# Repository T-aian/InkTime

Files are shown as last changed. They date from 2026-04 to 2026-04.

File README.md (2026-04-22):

# Documentație de Arhitectură și Inginerie Hardware: Sistemul Wearable InkTime

## 1. Introducere

Proiectul InkTime reprezintă o inițiativă tehnologică ambițioasă de a dezvolta un smartwatch open-source, optimizat pentru costuri reduse și manufacturabilitate la scară largă, fără a face compromisuri în ceea ce privește fiabilitatea sau performanța.

### 1.1. Structura Proiectului

- **Hardware/**: Găzduiește definițiile fundamentale ale circuitului. Aici se regăsesc fișierul schematic (.sch), alături de fișierul board-ului (.brd).
- **Manufacturing/**: Conține arhiva esențială pentru fabrica de PCB-uri (gerbers.zip), care include straturile de cupru, măștile de lipire (solder mask), stratul de inscripționare (silkscreen) și fișierele de găurire (Excellon drill files). De asemenea, acest director include fișierul Bill of Materials (.bom), detaliind componentele utilizate, și fișierul Pick and Place (.cpl), care mapează coordonatele carteziene (X, Y) și rotația fiecărei componente pentru echipamentele automate de asamblare.
- **Mechanical/**: Include modelul 3D integrat al dispozitivului în format .step și format nativ Fusion360. Acest model cuprinde PCB-ul populat cu componente, geometria exactă a bateriei Li-Po, ecranul LCD, motorul haptic (shaker) și șasiul carcasei într-o vizualizare detaliată de tip "exploded view".
- **Images/**: Un director vizual care conține randări fotorealiste ale PCBA-ului (Printed Circuit Board Assembly) și ilustrează modul de potrivire mecanică a plăcii în carcasă, servind drept ghid vizual pentru procedurile de asamblare manuală.

## 2. Arhitectura de Sistem și Diagrama Bloc

Filosofia de design a smartwatch-ului InkTime se bazează pe o topologie modulară, distribuită în jurul unui nod central de procesare (System-on-Chip). Diagrama bloc de mai jos ilustrează interconectarea magistralelor de date, a traseelor de putere și a modulelor periferice. Sistemul este împărțit în patru domenii funcționale majore: Domeniul de Putere (Power Tree), Domeniul de Procesare și Comunicație RF, Domeniul Senzorial și Domeniul Interfeței cu Utilizatorul (UI/HMI).

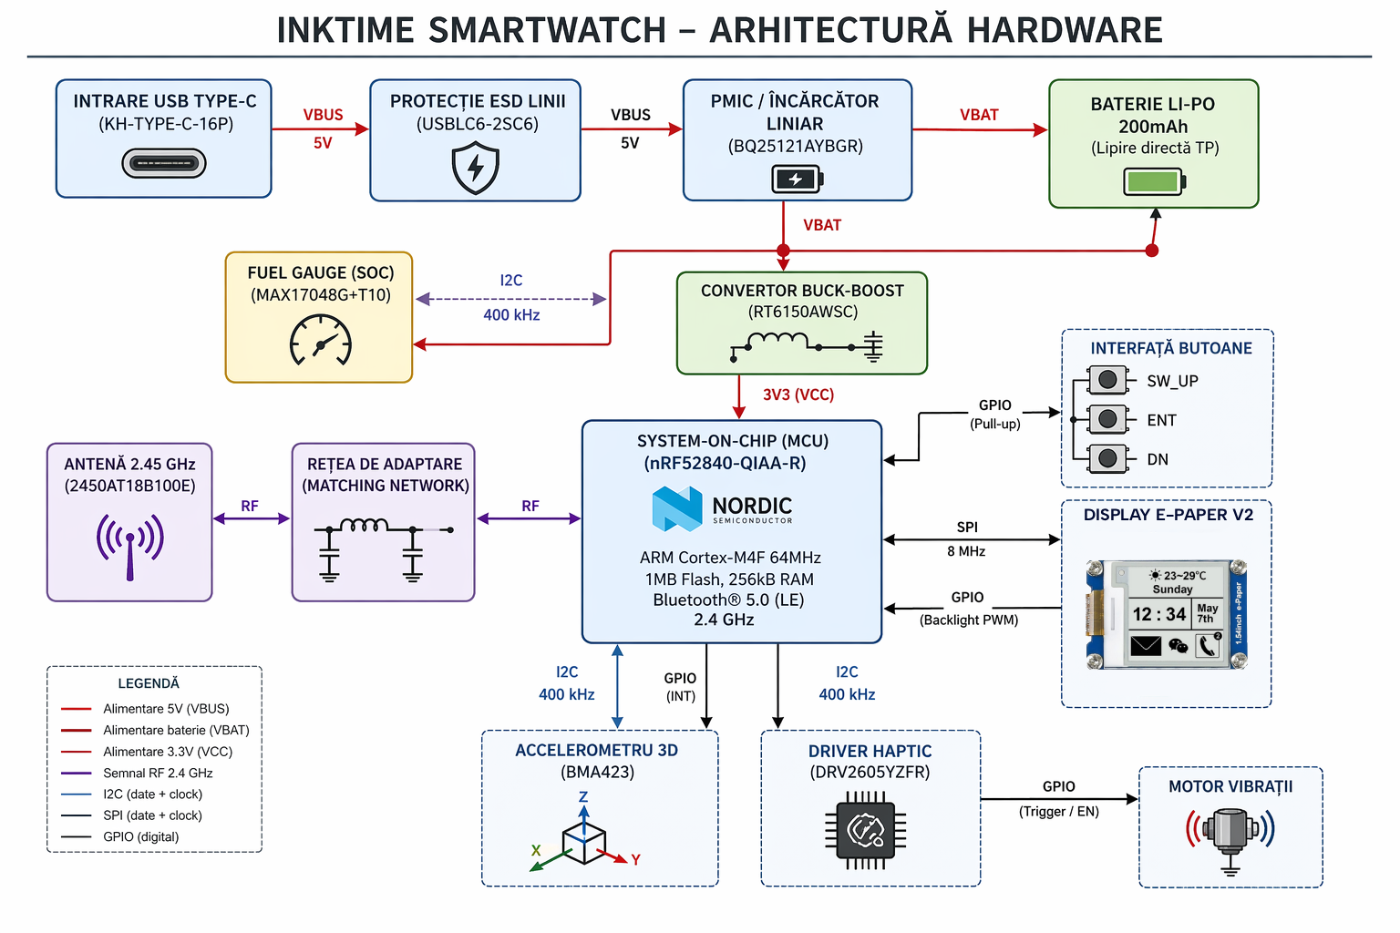
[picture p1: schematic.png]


Fluxul de operare este dictat de nRF52840, care gestionează stările de energie (Power States) ale întregului sistem. Modulul comunică asincron prin magistrala I2C (Inter-Integrated Circuit) cu senzorii (BMA423 pentru detecția mișcării, MAX17048 pentru starea bateriei, DRV2605 pentru feedback haptic) și sincron prin magistrala SPI (Serial Peripheral Interface) cu ecranul LCD. Etajul de alimentare separă procesul de încărcare (gestionat autonom de BQ25121A) de procesul de reglare a tensiunii (gestionat de RT6150AWSC), asigurând o tensiune logică de 3.3V indiferent de nivelul de descărcare al bateriei.

## 3. Bill of Materials (BOM)
Realizarea unui dispozitiv de masă la un cost competitiv impune o selecție a componentelor ancorată puternic în realitățile lanțului de aprovizionare (Supply Chain). Toate componentele majore au fost selectate din biblioteca producătorului asiatic JLCPCB, favorizând componentele "Basic" sau "Extended" aflate constant în stoc, evitând astfel întârzierile de aprovizionare.

De asemenea, pachetele fizice (footprints) au fost alese pentru a permite un asamblaj automatizat de mare viteză pe mașinile Pick and Place, respectând totodată cerința impusă de a utiliza exclusiv pachete SMD (Surface Mount Device).

| Componentă | Descriere funcțională | JLCPCB Part # | Link JLCPCB | Datasheet |
| --- | --- | --- | --- | --- |
| nRF52840-QIAA-R | System-on-Chip (SoC) ARM Cortex-M4F 64MHz, transceiver Bluetooth 5.0, 1MB Flash, 256KB RAM, pachet AQFN-73 | C190794 | [Link JLCPCB](https://jlcpcb.com/partdetail/NordicSemicon-NRF52840_QIAAR/C190794) | [https://files.seeedstudio.com/wiki/XIAO-BLE/Nano_BLE_MCU-nRF52840_PS_v1.1.pdf](https://files.seeedstudio.com/wiki/XIAO-BLE/Nano_BLE_MCU-nRF52840_PS_v1.1.pdf) |
| MAX17048G+T10 | Fuel Gauge pentru baterii Li-Ion (1 celulă), algoritm ModelGauge, interfață I2C, pachet TDFN-8 | C2682616 | [Link JLCPCB](https://jlcpcb.com/partdetail/C2682616) | [https://www.analog.com/media/en/technical-documentation/data-sheets/max17048-max17049.pdf](https://www.analog.com/media/en/technical-documentation/data-sheets/max17048-max17049.pdf) |
| BMA423 | Accelerometru MEMS triaxial, 12 biți, step counter hardware, pachet LGA-12 | C189517 | [Link JLCPCB](https://www.lcsc.com/product-detail/C189517.html) | [https://watchy.sqfmi.com/assets/files/BST-BMA423-DS000-1509600-950150f51058597a6234dd3eaafbb1f0.pdf](https://watchy.sqfmi.com/assets/files/BST-BMA423-DS000-1509600-950150f51058597a6234dd3eaafbb1f0.pdf) |
| DRV2605YZFR | Driver haptic smart-loop pentru motoare ERM/LRA, librărie Immersion, pachet DSBGA-9 | C81079 | [Link JLCPCB](https://www.lcsc.com/product-detail/C81079.html) | [https://www.ti.com/lit/ds/symlink/drv2605.pdf](https://www.ti.com/lit/ds/symlink/drv2605.pdf) |
| BQ25121AYBGR | PMIC + încărcător Li-Po ultra low power (max 300mA), Ship Mode, pachet DSBGA-25 | C111776 | [Link JLCPCB](https://jlcpcb.com/parts) | [https://www.ti.com/lit/ds/symlink/bq25121a.pdf](https://www.ti.com/lit/ds/symlink/bq25121a.pdf) |
| RT6150AWSC | Convertor DC-DC buck-boost (1.8V–5.5V → 3.3V), curent max 800mA, consum idle 60µA | C147971 | [Link JLCPCB](https://www.lcsc.com/product-detail/C147971.html) | [https://www.richtek.com/assets/product_file/RT6150A=RT6150B/DS6150AB-04.pdf](https://www.richtek.com/assets/product_file/RT6150A=RT6150B/DS6150AB-04.pdf) |
| KH-TYPE-C-16P | Conector USB Type-C mamă, 16 pini, SMD, profil redus, 3A | C709357 | [Link JLCPCB](https://jlcpcb.com/partdetail/KH-TYPE-C-16P/C709357) | N/A |
| USBLC6-2SC6 | Protecție ESD (TVS diode array), capacitance 2.5pF pentru linii USB | C7519 / C2827654 | [Link JLCPCB](https://jlcpcb.com/partdetail/STMicroelectronics-USBLC62SC6/C7519) | [https://www.st.com/resource/en/datasheet/usblc6-2.pdf](https://www.st.com/resource/en/datasheet/usblc6-2.pdf) |
| 2450AT18B100E | Antenă ceramică RF 2.45 GHz, eficiență ~76%, pachet SMD 1206 | C2836414 | [Link JLCPCB](https://jlcpcb.com/partdetail/JohansonTechnology-2450AT18B100/C2836414) | [https://www.johansontechnology.com/docs/1187/2450AT18B100_X8XXogU.pdf](https://www.johansontechnology.com/docs/1187/2450AT18B100_X8XXogU.pdf) |

## 4. Descrierea Exhaustivă a Funcționalității Hardware
Sistemul hardware a fost proiectat având ca prioritate absolută optimizarea balanței dintre performanța de calcul, capacitatea de interacțiune umană fluidă și un consum energetic de tip "ultra-low power". Modul în care aceste subsisteme interacționează determină direct fezabilitatea comercială a smartwatch-ului InkTime.
### 4.1. Nucleul de Procesare și Comunicație RF (nRF52840)
La baza sistemului se află integratul nRF52840-QIAA-R, un System-on-Chip (SoC) hibrid care combină logica unui microcontroler cu un transceiver radio de mare performanță. Funcționând la o frecvență de bază de 64 MHz, nucleul ARM Cortex-M4 include o unitate de calcul în virgulă mobilă (FPU - Floating Point Unit), esențială pentru procesarea accelerată a datelor senzoriale tridimensionale (cum ar fi cele generate de BMA423) și randarea elementelor grafice pe afișaj. Dispune de 1 MB memorie Flash internă și 256 KB memorie SRAM. Spațiul generos de memorie Flash permite integrarea sistemelor de operare de tip RTOS (precum Zephyr, frecvent utilizat în comunitatea open-source smartwatch) și implementarea de actualizări Over-The-Air (OTA) sigure.

Componenta de radiofrecvență a SoC-ului este extrem de performantă, suportând tehnologia Bluetooth 5.0 Low Energy (BLE), alături de protocoale precum Thread, Zigbee și rețele proprietare de 2.4 GHz. Dispozitivul are o sensibilitate de recepție de -95 dBm la 1 Mbps și poate emite semnale la o putere configurabilă de la -20 dBm până la +8 dBm. Această versatilitate asigură că ceasul poate menține o legătură stabilă cu un terminal mobil (ex. smartphone) chiar și în medii electromagnetice congestionate, minimizând totodată consumul bateriei adaptând puterea de transmisie. Securitatea pachetelor de date BLE este garantată de coprocesorul intern ARM TrustZone CryptoCell 310, care realizează criptare hardware AES/ECB asincron, degrevând procesorul principal.

Antena ceramică tip SMD (2450AT18B100E) este montată la extremitatea plăcii și este un dispozitiv de tip LTCC (Low Temperature Co-fired Ceramic), proiectat de Johanson Technology. Oferind o eficiență de 76%, antena necesită un design restrictiv al planului de masă pentru a nu-și altera impedanța caracteristică de 50 Ohmi.

### 4.2. Topologia de Alimentare și Managementul Bateriei (Power Delivery Network)

Tensiunea unei baterii clasice Litiu-Polimer (Li-Po) fluctuează considerabil în timpul ciclului său de descărcare, de la o valoare maximă de ~4.2V (complet încărcată) până la o tensiune de cut-off de aproximativ 3.0V. Pentru ca ecranul IPS și procesorul să ruleze constant, au nevoie de o sursă stabilă de energie. Aici intervine arhitectura "Power Tree" a dispozitivului InkTime.

### Etajul de Încărcare și Protecție (BQ25121A și USBLC6-2SC6):

Energia pătrunde în sistem prin intermediul conectorului KH-TYPE-C-16P, o versiune orizontală SMD care susține curenți nominali ridicați și care a fost preferată pentru profilul său plat. Liniile de date și alimentare ale portului USB sunt expuse mediului extern, devenind vulnerabile la descărcări electrostatice (ESD). Circuitul USBLC6-2SC6, conectat imediat după port, clamp-ează aceste tensiuni tranzitorii violente (clamping voltage de 17V) redirecționându-le în masă. Cu o capacitanță parazită de numai 2.5pF, acest cip nu degradează integritatea semnalului.

Tensiunea de 5V preluată (VBUS) este apoi rutată către circuitul de management al bateriei BQ25121AYBGR. Acest IC ultra-integrat a fost selectat în detrimentul soluțiilor clasice (precum TP4056) datorită capabilităților avansate de gestionare I2C și a unui consum de repaus (quiescent current) neglijabil. BQ25121A poate încărca bateria cu un curent controlat (maxim 300 mA), implementând ciclul standard CC-CV (Constant Current / Constant Voltage), dar mai important, dispune de un "Ship Mode". Prin activarea acestui mod, ceasul poate fi complet deconectat electronic de la baterie în timpul transportului și stocării în depozite, scăzând consumul bateriei sub 50nA, eliminând astfel riscul ca produsul să ajungă la consumator cu bateria "moartă".

### Etajul de Reglare a Tensiunii (RT6150AWSC):

Întreaga placă electronică funcționează la tensiunea standard de 3.3V (VCC / 3V3). Pentru a prelua variația bateriei de la 3.0V la 4.2V și a furniza constant 3.3V fără a disipa restul de putere ca pierdere termică (așa cum ar face un regulator liniar LDO), a fost integrat convertorul DC-DC Buck-Boost RT6150AWSC. Frecvența sa de comutație de 1 MHz permite utilizarea unor componente pasive magnetice (inductoare) mult mai mici, vitale pentru un design de tip smartwatch. Convertorul dispune de un "Power Save Mode" (PSM), care, în perioadele de consum redus, își scade frecvența de operare și trage din baterie un curent pasiv de doar 60 µA, menținând eficiențe mari la curenți mici.

### Monitorizarea Autonomiei (MAX17048G+T10):
În mod tradițional, monitorizarea capacității unei baterii implică inserarea unui rezistor tip "shunt" (coulomb counter) pe traseul de retur, ceea ce introduce pierderi resistive constante. InkTime utilizează integratul MAX17048G+T10. Acest fuel-gauge citește exclusiv tensiunea celulei (VCELL) și folosește un model matematic proprietar (ModelGauge™) pentru a estima Starea de Încărcare (State-of-Charge / SOC) cu o toleranță a erorii extrem de redusă, raportând datele către nRF52840 pe magistrala I2C. Prin eliminarea rezistorului de măsurare și o stare internă "Hibernate" în care consumă doar 3 µA, se economisește spațiu vital pe PCB și energie prețioasă.

### 4.3. Modulul Senzorial (Accelerometrul BMA423)
Pentru monitorizarea cinematică a purtătorului s-a implementat accelerometrul MEMS digital BMA423, proiectat de Bosch Sensortec. Acest senzor din clasa senzorilor "inteligenți" a fost creat special pentru industria wearable. În locul eșantionării constante și transferării a mii de pachete de date brute (Raw Acceleration Data) pe magistrala I2C către MCU – proces ce ar drena rapid bateria – BMA423 dispune de logică procesuală internă.
Funcția sa nativă de pedometru (Step Counter) analizează algoritmic tiparele de accelerație și numără pașii independent, menținând un consum total de putere redus până la pragul de 13 µA – 25 µA. Informația este stocată într-un buffer intern (FIFO de 1 kByte) de unde poate fi interogată ocazional de MCU. Suplimentar, funcțiile hardware de recunoaștere a mișcării identifică acțiunile de ridicare a brațului spre ochi ("Tilt-on-Wrist") sau bătăi ("Tap/Double Tap") și emit un impuls asincron pe un pin de întrerupere dedicat (INT), ordonând procesorului nRF52840 să iasă din modul System OFF/ON Sleep.

### 4.5. Feedback Haptic Avansat (DRV2605YZFR)

Alerta tactilă a utilizatorului trebuie să fie precisă, evitându-se "zgomotul" tactil al motoarelor dezechilibrate tradiționale. Implementarea include integratul DRV2605YZFR de la Texas Instruments, un driver haptic de înaltă finețe în pachet miniatural DSBGA (chip-scale package). Acest circuit, comunicând prin I2C, integrează o arhitectură de control "Smart-Loop" ce scurtează masiv timpii de accelerare (Startup Time ~ 0.7ms) și frânare ai motorului.
Mecanismul intern monitorizează constant forța contra-electromotoare (BEMF) indusă de motor pe liniile de acționare. Printr-o secvență de calibrare automată, DRV2605 detectează frecvența de rezonanță mecanică a actuatoarelor de tip LRA (Linear Resonant Actuator) și le acționează precis pe acea frecvență, extrăgând forță vibratorie dublă și economisind până la 50% din energia pe care ar fi risipit-o un driver liniar clasic cu punte H. Integratul include o memorie pre-încărcată cu peste 100 de efecte tactile licențiate de compania Immersion, permițând dezvoltatorilor software să selecteze simplu (via I2C) profilul de vibrație dorit (e.g., un „click” scurt de confirmare, o vibrație lungă de alertă), în loc să folosească comutații PWM manuale de la microcontroler. Când nu rulează nicio secvență, consumul driver-ului decade la sub 2 µA.

## 5. Alocarea și Justificarea Mapării Pinilor la nRF52840

SoC-ul nRF52840 oferă o matrice flexibilă (crossbar) pentru alocarea funcțiilor periferice (I2C, SPI, UART, PWM) către majoritatea pinilor GPIO. Cu toate acestea, această libertate este guvernată de reguli fizice imuabile detaliate în Specificațiile de Produs Nordic. Anumiți pini (e.g. P0.02, P0.03, P0.30, P1.15 etc.) sunt clasați arhitectural ca "Standard drive, low frequency I/O only", fiind optimizați exclusiv pentru semnale care nu depășesc 10 kHz. Ignorarea acestei limitări și forțarea unor magistrale rapide (cum ar fi clock-ul SPI la 8 MHz) pe acești pini va conduce la distorsiuni de formă a undei, diafonie radio (interferențe cu semnalul BLE de 2.4GHz) și emisii electromagnetice care pot eșua un test de certificare FCC/CE.

## 6. Analiza Bugetului Energetic și Estimarea Autonomiei Bateriei
Pentru a garanta că proiectul InkTime reprezintă o alternativă fezabilă pe piață, trebuie obținut un echilibru delicat între volumul intern restrâns al dispozitivului – care dictează utilizarea unei baterii Li-Po miniaturale de aproximativ 200 mAh (tensiune nominală 3.7V, tensiune maximă 4.2V) – și consumul diverselor componente electronice.

Mai jos prezentăm un calcul teoretic detaliat al consumului, divizat în cele două stări absolute de utilizare: Starea de Repaus (Sleep Mode) și Starea Activă (Peak Load). Calculele sunt preluate din informațiile stricte oferite de foile de catalog oficiale (Datasheets).

### 6.1. Consumul în Modul de Repaus (System Sleep State)

Un smartwatch își petrece majoritatea timpului (~90–95%) în stare de repaus, cu ecranul oprit. În acest mod:

- sistemul rulează în System ON Sleep (specific nRF52840)
- RAM-ul rămâne alimentat
- RTC-ul este activ
- BLE funcționează în mod Advertising periodic

Consum:
| Componentă | Consum tipic | Condiție / Justificare |
| --- | --- | --- |
| nRF52840 SoC | ~1.5 µA | System ON, CPU în WFI (Wait For Interrupt), RTC activ |
| Radio BLE | ~3.8 µA | Advertising periodic (interval ~10s) |
| BMA423 | ~13.0 µA | Low-power mode, sampling redus (~50 Hz), step detection activ |
| MAX17048 | ~3.0 µA | Hibernate mode, măsurători rare |
| DRV2605 | ~1.75 µA | Standby complet (shutdown) |
| BQ25121A | ~0.7 µA | Leakage cu USB deconectat |
| RT6150AWSC | ~60.0 µA | Quiescent current (DC-DC activ în Power Save Mode) |
| PCB (rezidual) | ~10.0 µA | Leakage pasive + pull-up-uri I2C |

**Consum total:** 
`TOTAL SLEEP ≈ 93.75 µA (0.093 mA)`

### 6.2. Consumul în Mod Activ (Peak Load State)

În modul activ (utilizatorul interacționează cu ceasul):
- display-ul este aprins
- BLE transmite date
- motorul haptic poate fi activ

| Componentă | Consum Peak  | Condiție / Justificare |
| --- | --- | --- |
| Display e-ink | ~5 – 15 mA (peak) | Doar în timpul refresh-ului (~200–500 ms). Consum ≈ 0 între refresh-uri |
| nRF52840 (CPU + BLE) | ~4.8 – 15 mA | TX BLE + procesare SPI pentru display |
| BMA423 | ~0.15 mA | High-performance mode (gesturi complexe) |
| DRV2605 + motor | ~60 – 80 mA  | Vibrație activă (ERM/LRA startup) |

**Consum total:** 
`TOTAL ACTIVE ≈ 10 – 90 mA`

### 6.3 Durată de viață Estimativă

Pe baza bugetelor de consum estimate, autonomia sistemului poate fi aproximată considerând un scenariu realist de utilizare: ~95% din timp în modul sleep (~0.093 mA) și ~5% în modul activ (~50 mA mediu). Curentul mediu rezultat este:

`I_med ≈ 0.95 × 0.093 mA + 0.05 × 50 mA ≈ 2.58 mA`

Pentru o baterie Li-Po de 200 mAh, rezultă o durată de funcționare de aproximativ:

`T ≈ 200 mAh / 5.1 mA ≈ 77 ore (~3-4 zile)`

În practică, ținând cont de pierderile din conversia de tensiune (eficiența ~90% a regulatorului) și variațiile de utilizare (ex.vibrații frecvente), autonomia reală va fi în intervalul 4-5 zile, ceea ce este tipic pentru un smartwatch cu e-ink și funcții BLE active.

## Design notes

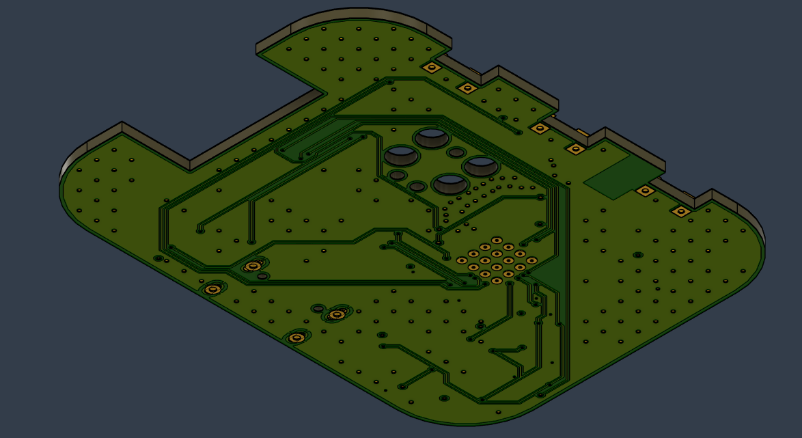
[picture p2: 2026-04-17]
Images/PCB_Bottom.png

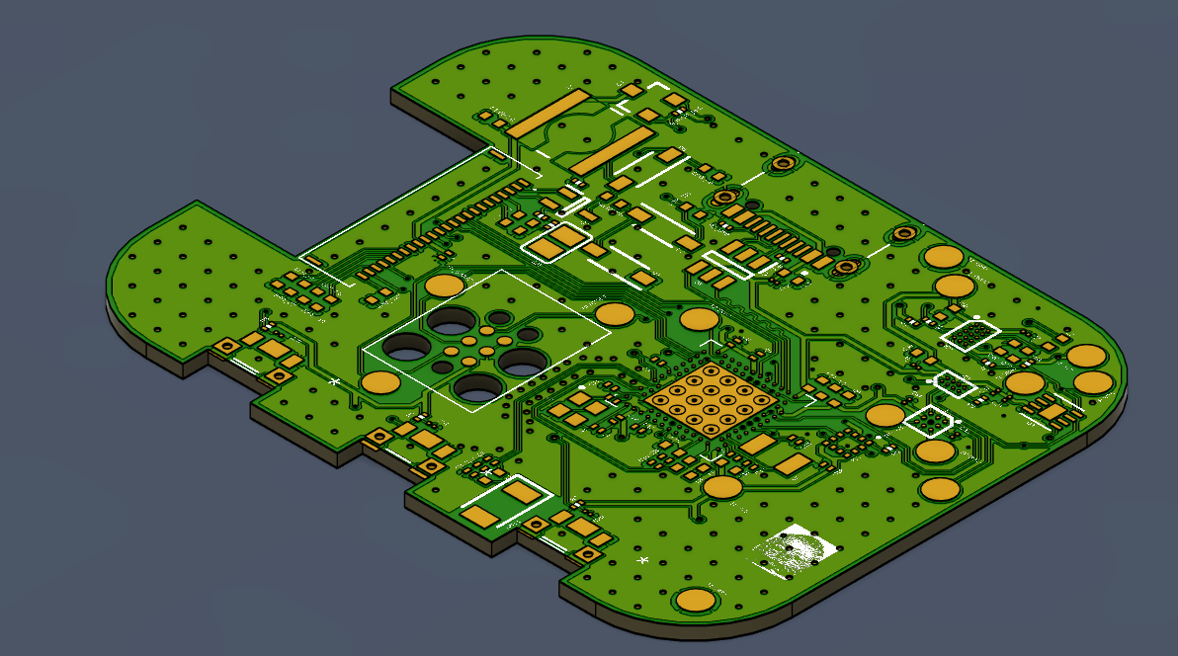
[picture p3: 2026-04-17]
Images/PCB_Top.png

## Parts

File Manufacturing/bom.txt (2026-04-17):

Partlist exported from Fusion Hub: Biles   Project: Default Project  Board: InkTime at 17/04/2026 13:04

Qty Value                                                   Device                                                                       Package                                                                                                                Parts                                                                                                                      Description                                                                                                               ARROW_PART_NUMBER ARROW_PRICE-STOCK                                                                                AVAILABILITY CHECK_PRICES                                                                       COPYRIGHT                                                DESCRIPTION                                                                                                                                                                         DIGI-KEY_PART_NUMBER_1                    DIGI-KEY_PART_NUMBER_2 DIGI-KEY_PART_NUMBER_3                              HEIGHT  MANUFACTURER_NAME   MANUFACTURER_PART_NUMBER MF                 MFR_NAME          MOUSER_PART_NUMBER MOUSER_PRICE-STOCK                                                                                           MP                                                                                                       PACKAGE                     POPULARITY PRICE            PROD_ID                      PURCHASE-URL                                                                                                                               SNAPEDA_LINK                                                                      TP_SIGNAL_NAME VALUE                                                                                                                                          
1                                                           ESP32_C6_LIBRARY_7_JUMPER_SJ                                                 ESP32_C6_LIBRARY_7_JUMPER_SJ                                                                                           SJ1                                                                                                                        SMD solder JUMPER                                                                                                                                                                                                                                                                                                                                                                                                                                                                                                                                                                                                                                                                                                                                                                                                                                                                                                                                                                                                                                                             3                                                                                                                                                                                                                                                                                                                                                                                                                                                   
1                                                           NORDIC_NRF_2_INDUCTOR_0402_L                                                 NORDIC_NRF_2_RESC0402_L                                                                                                L7                                                                                                                         Generic chip inductor                                                                                                                                                                                                                                                                                                                                                                                                                                                                                                                                                                                                                                                                                                                                                                                                                                                                                                                                                                                                                                                                                                                                                                                                                                                                                                                                                                                                                                                                                                             
3   0                                                       CPF0201D7K68C1_CPF0201D7K68C1                                                CPF0201D7K68C1_0201                                                                                                    R2, R3, R4                                                                                                                 7.68k 0201 Thin Film Surface Mount Fixed Resistor +/-0.5% 0.031W CPF0201D7K68C1                                                                                                                                                                                                                                                                                                                                                                                                                                                                                                                                                                                                                                                                                                                                                                                                                                                                                                                                                                                                                                                                                                                                                                                                                                                                                                                                                                                                                                                   
4   0.1µF                                                   GRM011R60J152KE01L_2_GRM011R60J152KE01L                                      GRM011R60J152KE01L_2_CAPC0201X13N                                                                                      C23, C27, C34, C42                                                                                                         Check availability                                                                                                                                                                                                                           In Stock     https://www.snapeda.com/parts/GRM011R60J152KE01L/Murata/view-part/?ref=eda                                                                                                                        SMD Capacitor X5R(EIA) with Capacitance: 1500pF Tol. 10%. Rated Voltage: 6.3Vdc                                                                                                                                                                                                                         Murata                                                                                                                                                               GRM011R60J152KE01L                                                                                       0201 Murata                            None                                                                                                                                                                                     https://www.snapeda.com/parts/GRM011R60J152KE01L/Murata/view-part/?ref=snap                                                                                                                                                                     
1   0.1µF/50V                                               NORDIC_NRF_3_CAPACITOR_0201_L                                                NORDIC_NRF_3_RESC0201_L                                                                                                EPD_C5                                                                                                                     Generic chip capacitor                                                                                                                                                                                                                                                                                                                                                                                                                                                                                                                                                                                                                                                                                                                                                                                                                                                                                                                                                                                                                                                                                                                                                                                                                                                                                                                                                                                                                                                                                                            
1   0.47                                                    CPF0201D7K68C1_CPF0201D7K68C1                                                CPF0201D7K68C1_0201                                                                                                    R1_EP_DR                                                                                                                   7.68k 0201 Thin Film Surface Mount Fixed Resistor +/-0.5% 0.031W CPF0201D7K68C1                                                                                                                                                                                                                                                                                                                                                                                                                                                                                                                                                                                                                                                                                                                                                                                                                                                                                                                                                                                                                                                                                                                                                                                                                                                                                                                                                                                                                                                   
1   1.0µF                                                   NORDIC_NRF_3_CAPACITOR_0402_L                                                NORDIC_NRF_3_RESC0402_L                                                                                                C15                                                                                                                        Generic chip capacitor                                                                                                                                                                                                                                                                                                                                                                                                                                                                                                                                                                                                                                                                                                                                                                                                                                                                                                                                                                                                                                                                                                                                                                                                                                                                                                                                                                                                                                                                                                            
5   100nF                                                   NORDIC_NRF_3_CAPACITOR_0201_L                                                NORDIC_NRF_3_RESC0201_L                                                                                                C5, C7, C8, C12, C19                                                                                                       Generic chip capacitor                                                                                                                                                                                                                                                                                                                                                                                                                                                                                                                                                                                                                                                                                                                                                                                                                                                                                                                                                                                                                                                                                                                                                                                                                                                                                                                                                                                                                                                                                                            
1   100pF                                                   NORDIC_NRF_3_CAPACITOR_0201_L                                                NORDIC_NRF_3_RESC0201_L                                                                                                C11                                                                                                                        Generic chip capacitor                                                                                                                                                                                                                                                                                                                                                                                                                                                                                                                                                                                                                                                                                                                                                                                                                                                                                                                                                                                                                                                                                                                                                                                                                                                                                                                                                                                                                                                                                                            
6   10K                                                     CPF0201D7K68C1_CPF0201D7K68C1                                                CPF0201D7K68C1_0201                                                                                                    R2_EP_DR, R5, R7, R8, R9, R_PWR_EPD                                                                                        7.68k 0201 Thin Film Surface Mount Fixed Resistor +/-0.5% 0.031W CPF0201D7K68C1                                                                                                                                                                                                                                                                                                                                                                                                                                                                                                                                                                                                                                                                                                                                                                                                                                                                                                                                                                                                                                                                                                                                                                                                                                                                                                                                                                                                                                                   
1   10µH                                                    NORDIC_NRF_2_INDUCTOR_0402_L                                                 NORDIC_NRF_2_RESC0402_L                                                                                                L2                                                                                                                         Generic chip inductor                                                                                                                                                                                                                                                                                                                                                                                                                                                                                                                                                                                                                                                                                                                                                                                                                                                                                                                                                                                                                                                                                                                                                                                                                                                                                                                                                                                                                                                                                                             
3   10µF                                                    NORDIC_NRF_3_CAPACITOR_0402_L                                                NORDIC_NRF_3_RESC0402_L                                                                                                C1-EP-DR, C24, C39                                                                                                         Generic chip capacitor                                                                                                                                                                                                                                                                                                                                                                                                                                                                                                                                                                                                                                                                                                                                                                                                                                                                                                                                                                                                                                                                                                                                                                                                                                                                                                                                                                                                                                                                                                            
4   12pF                                                    NORDIC_NRF_3_CAPACITOR_0201_L                                                NORDIC_NRF_3_RESC0201_L                                                                                                C1, C2, C17, C18                                                                                                           Generic chip capacitor                                                                                                                                                                                                                                                                                                                                                                                                                                                                                                                                                                                                                                                                                                                                                                                                                                                                                                                                                                                                                                                                                                                                                                                                                                                                                                                                                                                                                                                                                                            
1   15nH                                                    NORDIC_NRF_2_INDUCTOR_0402_L                                                 NORDIC_NRF_2_RESC0402_L                                                                                                L3                                                                                                                         Generic chip inductor                                                                                                                                                                                                                                                                                                                                                                                                                                                                                                                                                                                                                                                                                                                                                                                                                                                                                                                                                                                                                                                                                                                                                                                                                                                                                                                                                                                                                                                                                                             
2   1pF                                                     NORDIC_NRF_3_CAPACITOR_0201_L                                                NORDIC_NRF_3_RESC0201_L                                                                                                C3, C4                                                                                                                     Generic chip capacitor
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

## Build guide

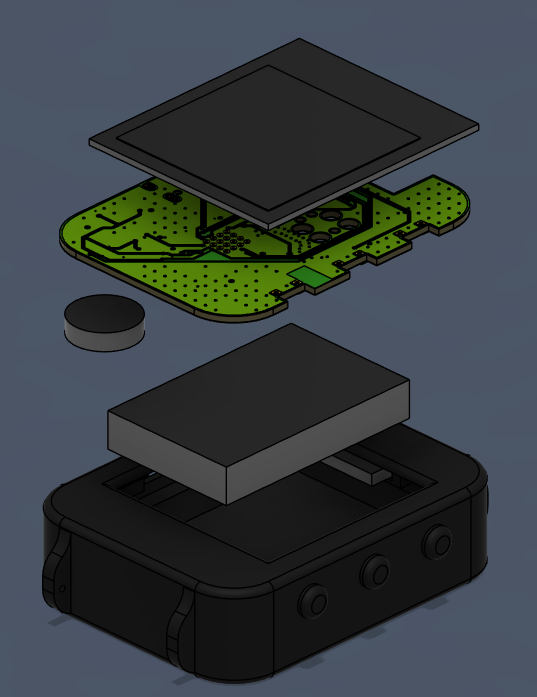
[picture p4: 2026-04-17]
Images/Assembly Exploded.png

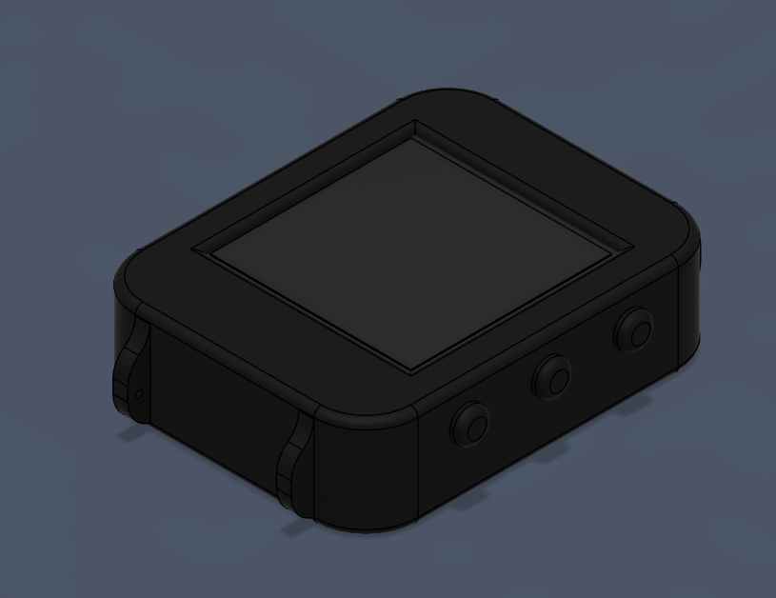
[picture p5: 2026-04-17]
Images/Assembly.png

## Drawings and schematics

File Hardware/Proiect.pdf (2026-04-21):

68uH | 10K
RESE | GDR

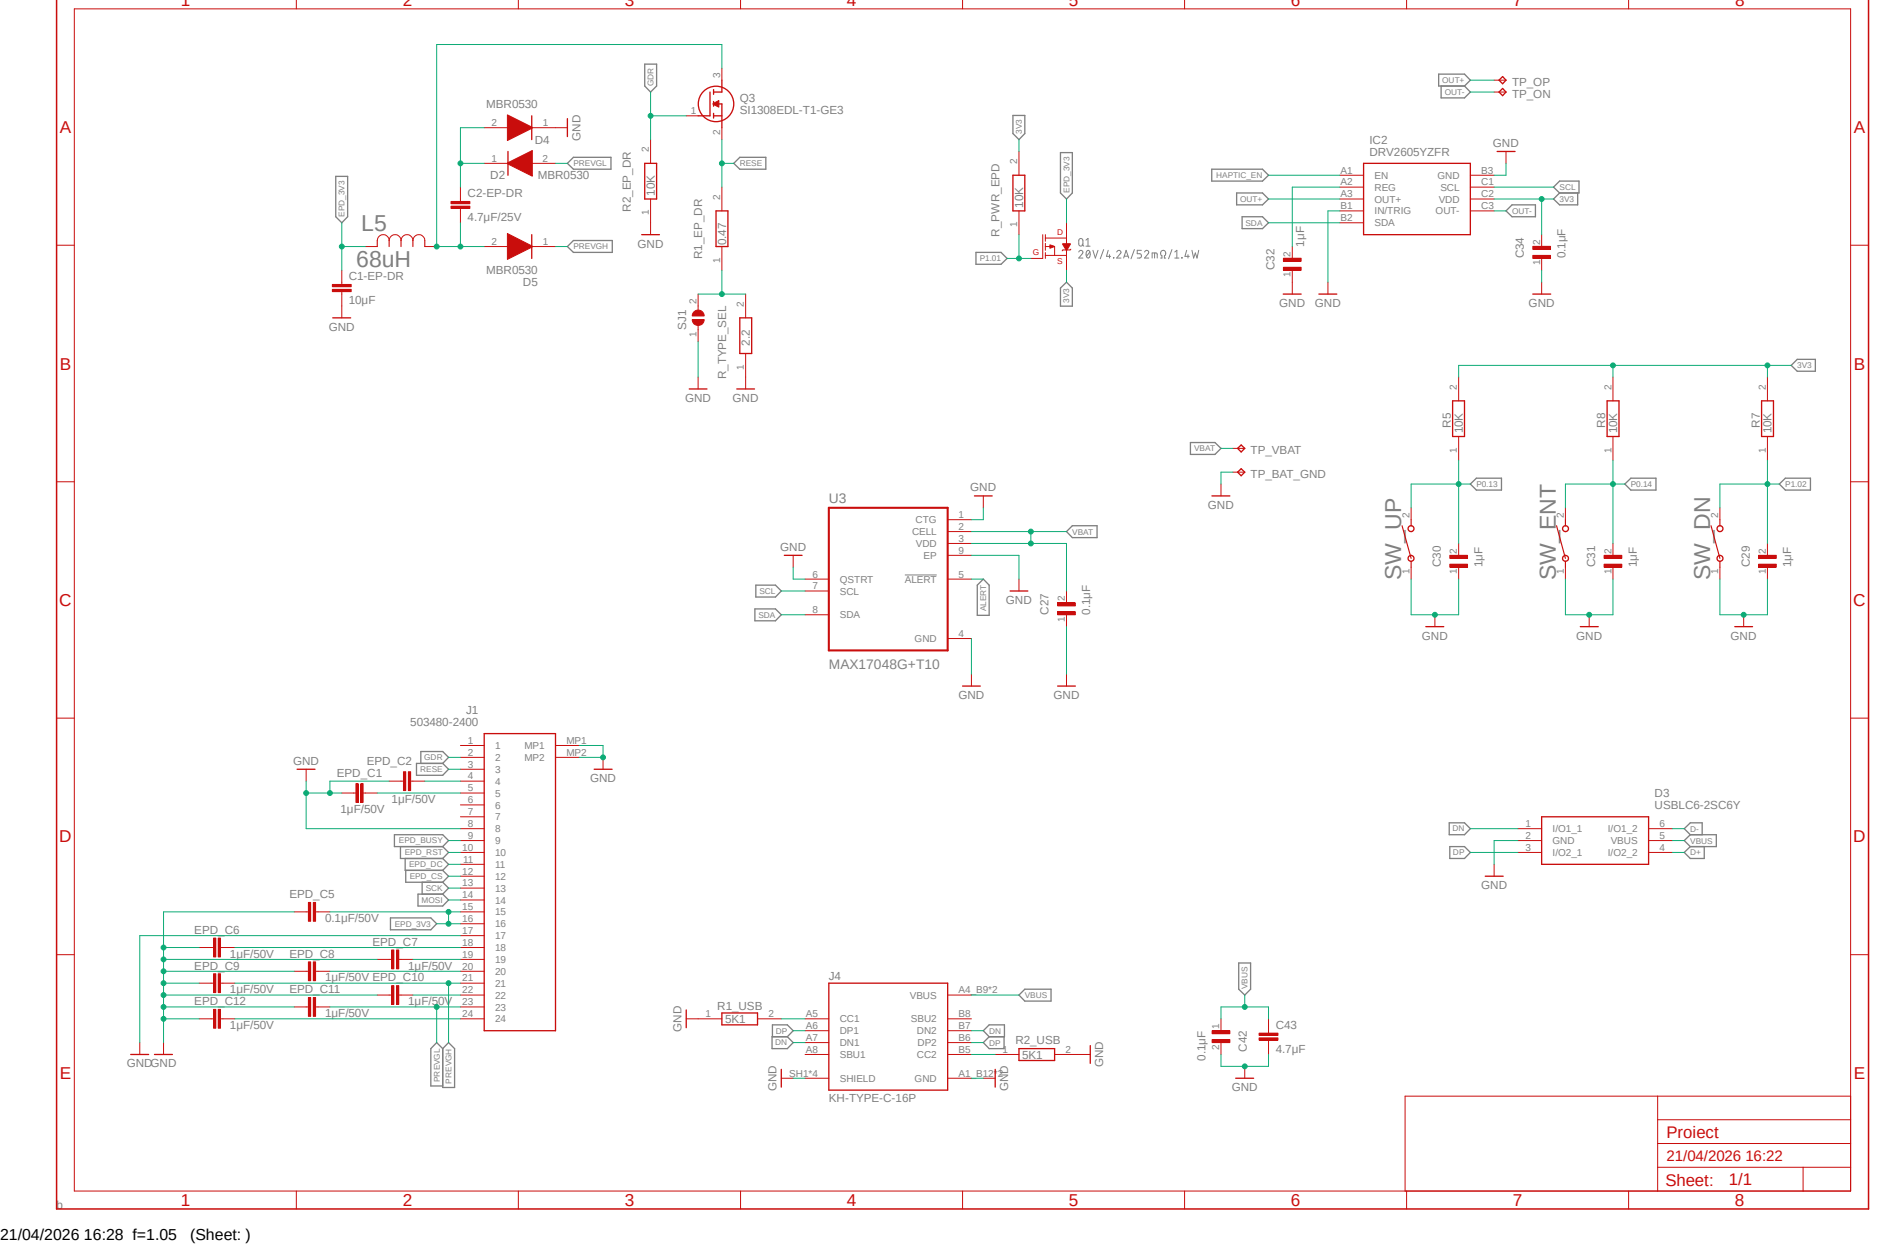
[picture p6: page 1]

EPD_C7 | 18 18

1μF/50V EPD_C8 | 19 19
EPD_C9 | 1μF/50V | 20 20
1μF/50V EPD_C11 | | 22 22
EPD_C12 | 1μF/50V | | 23 23

A

A

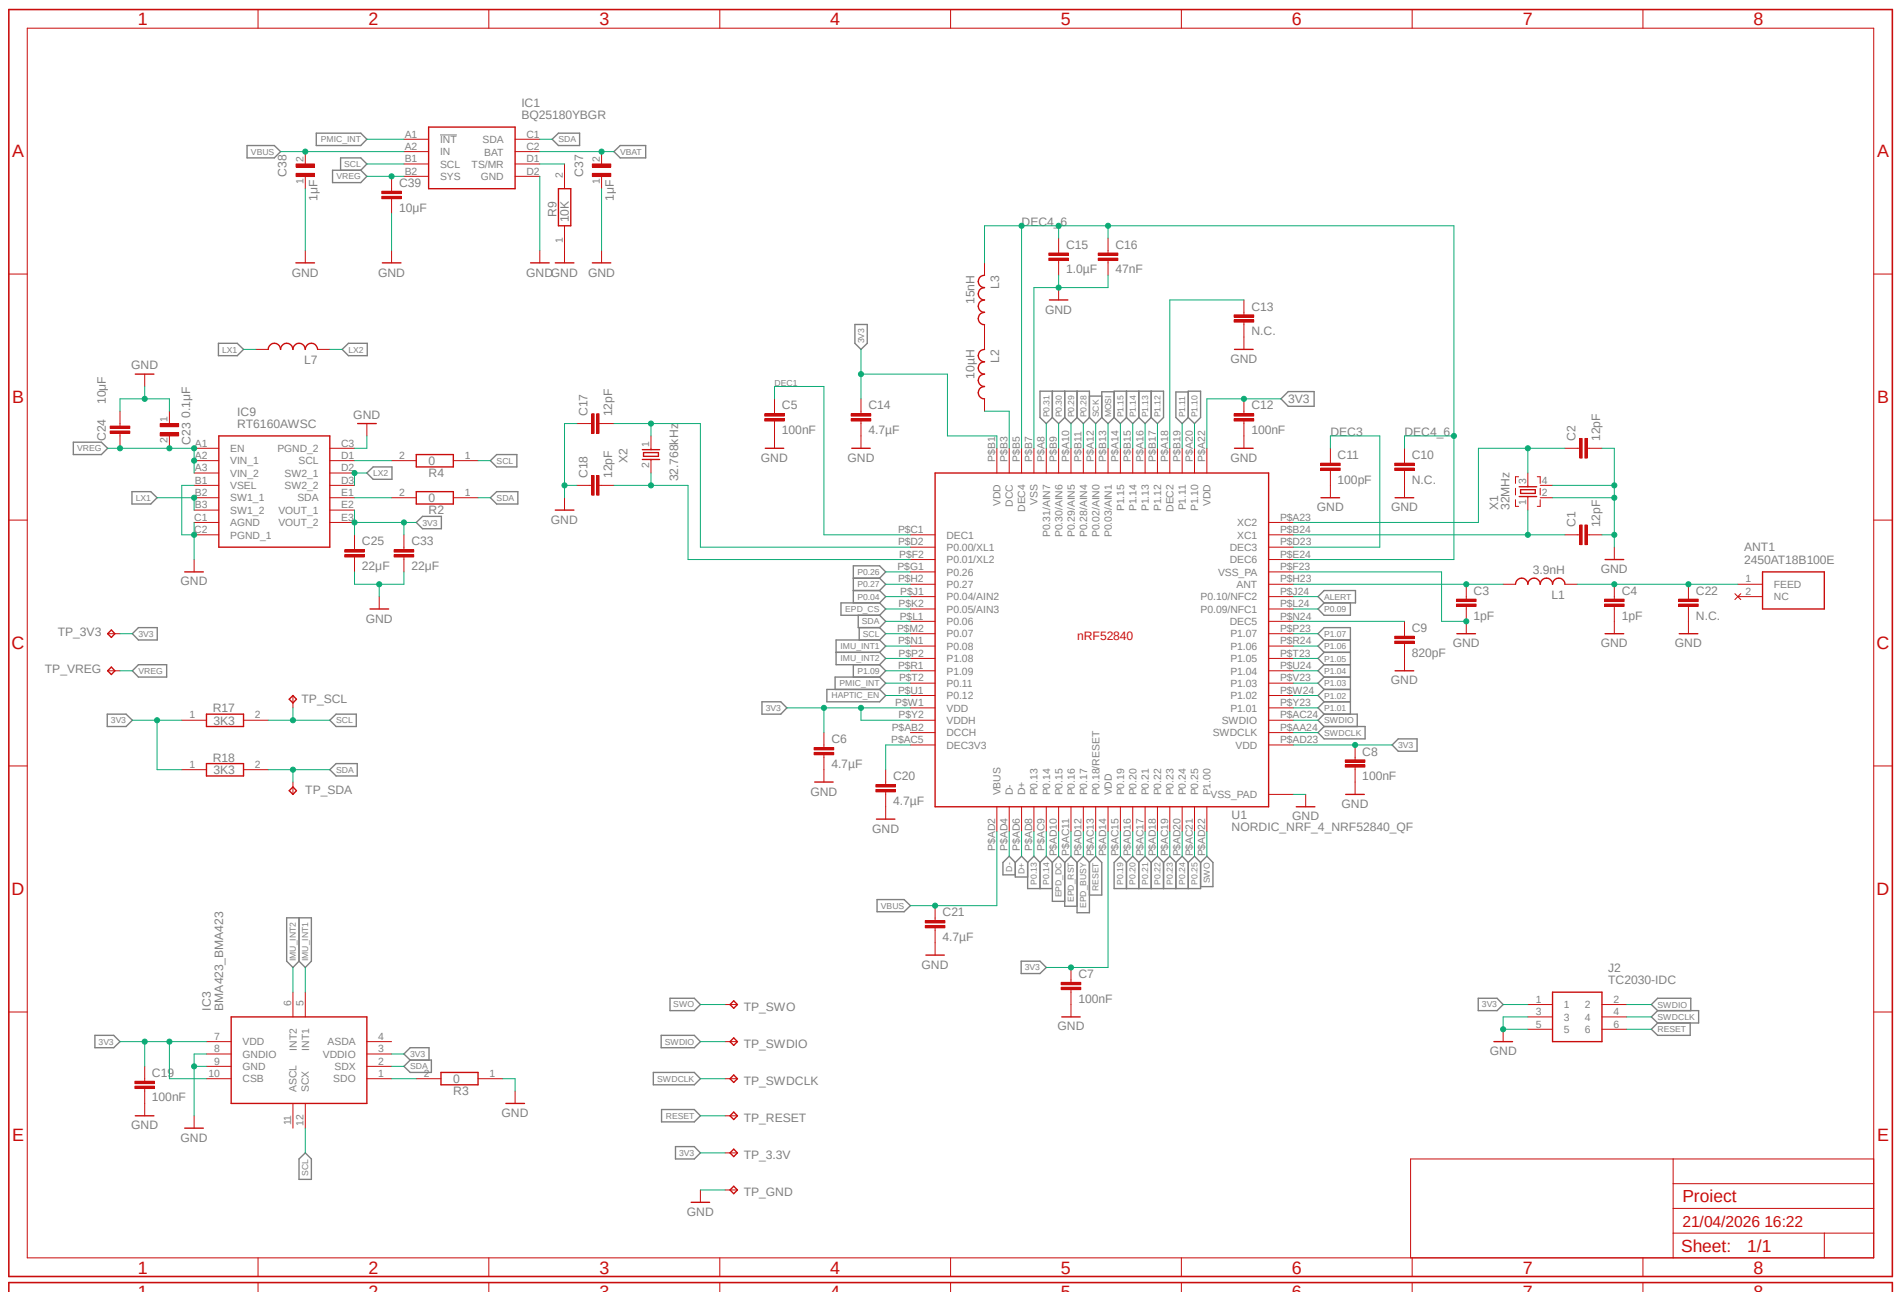
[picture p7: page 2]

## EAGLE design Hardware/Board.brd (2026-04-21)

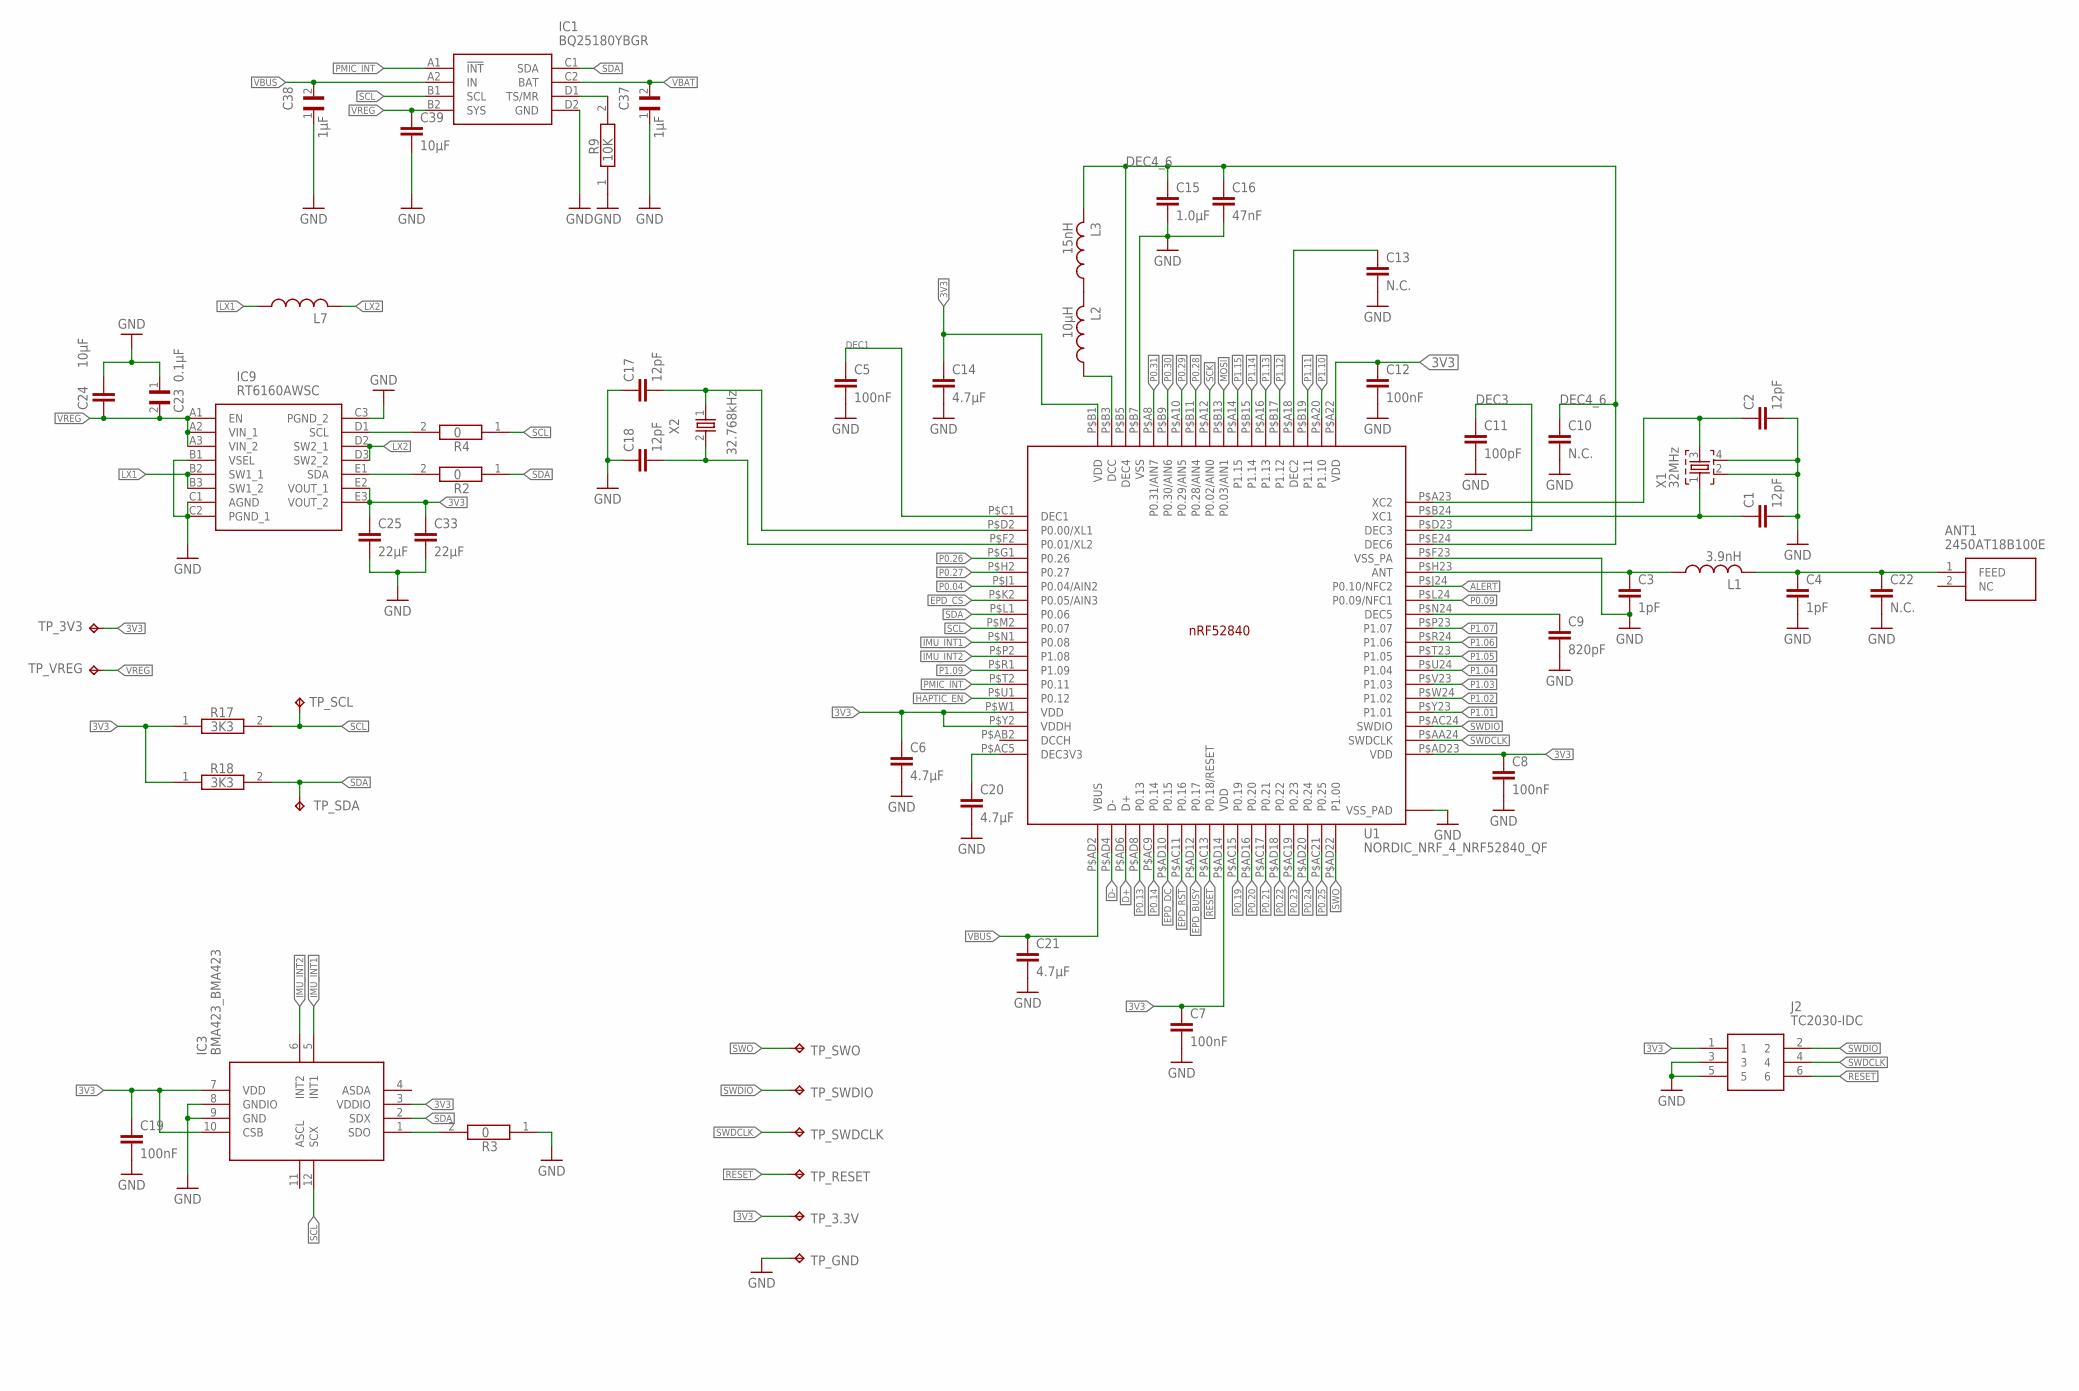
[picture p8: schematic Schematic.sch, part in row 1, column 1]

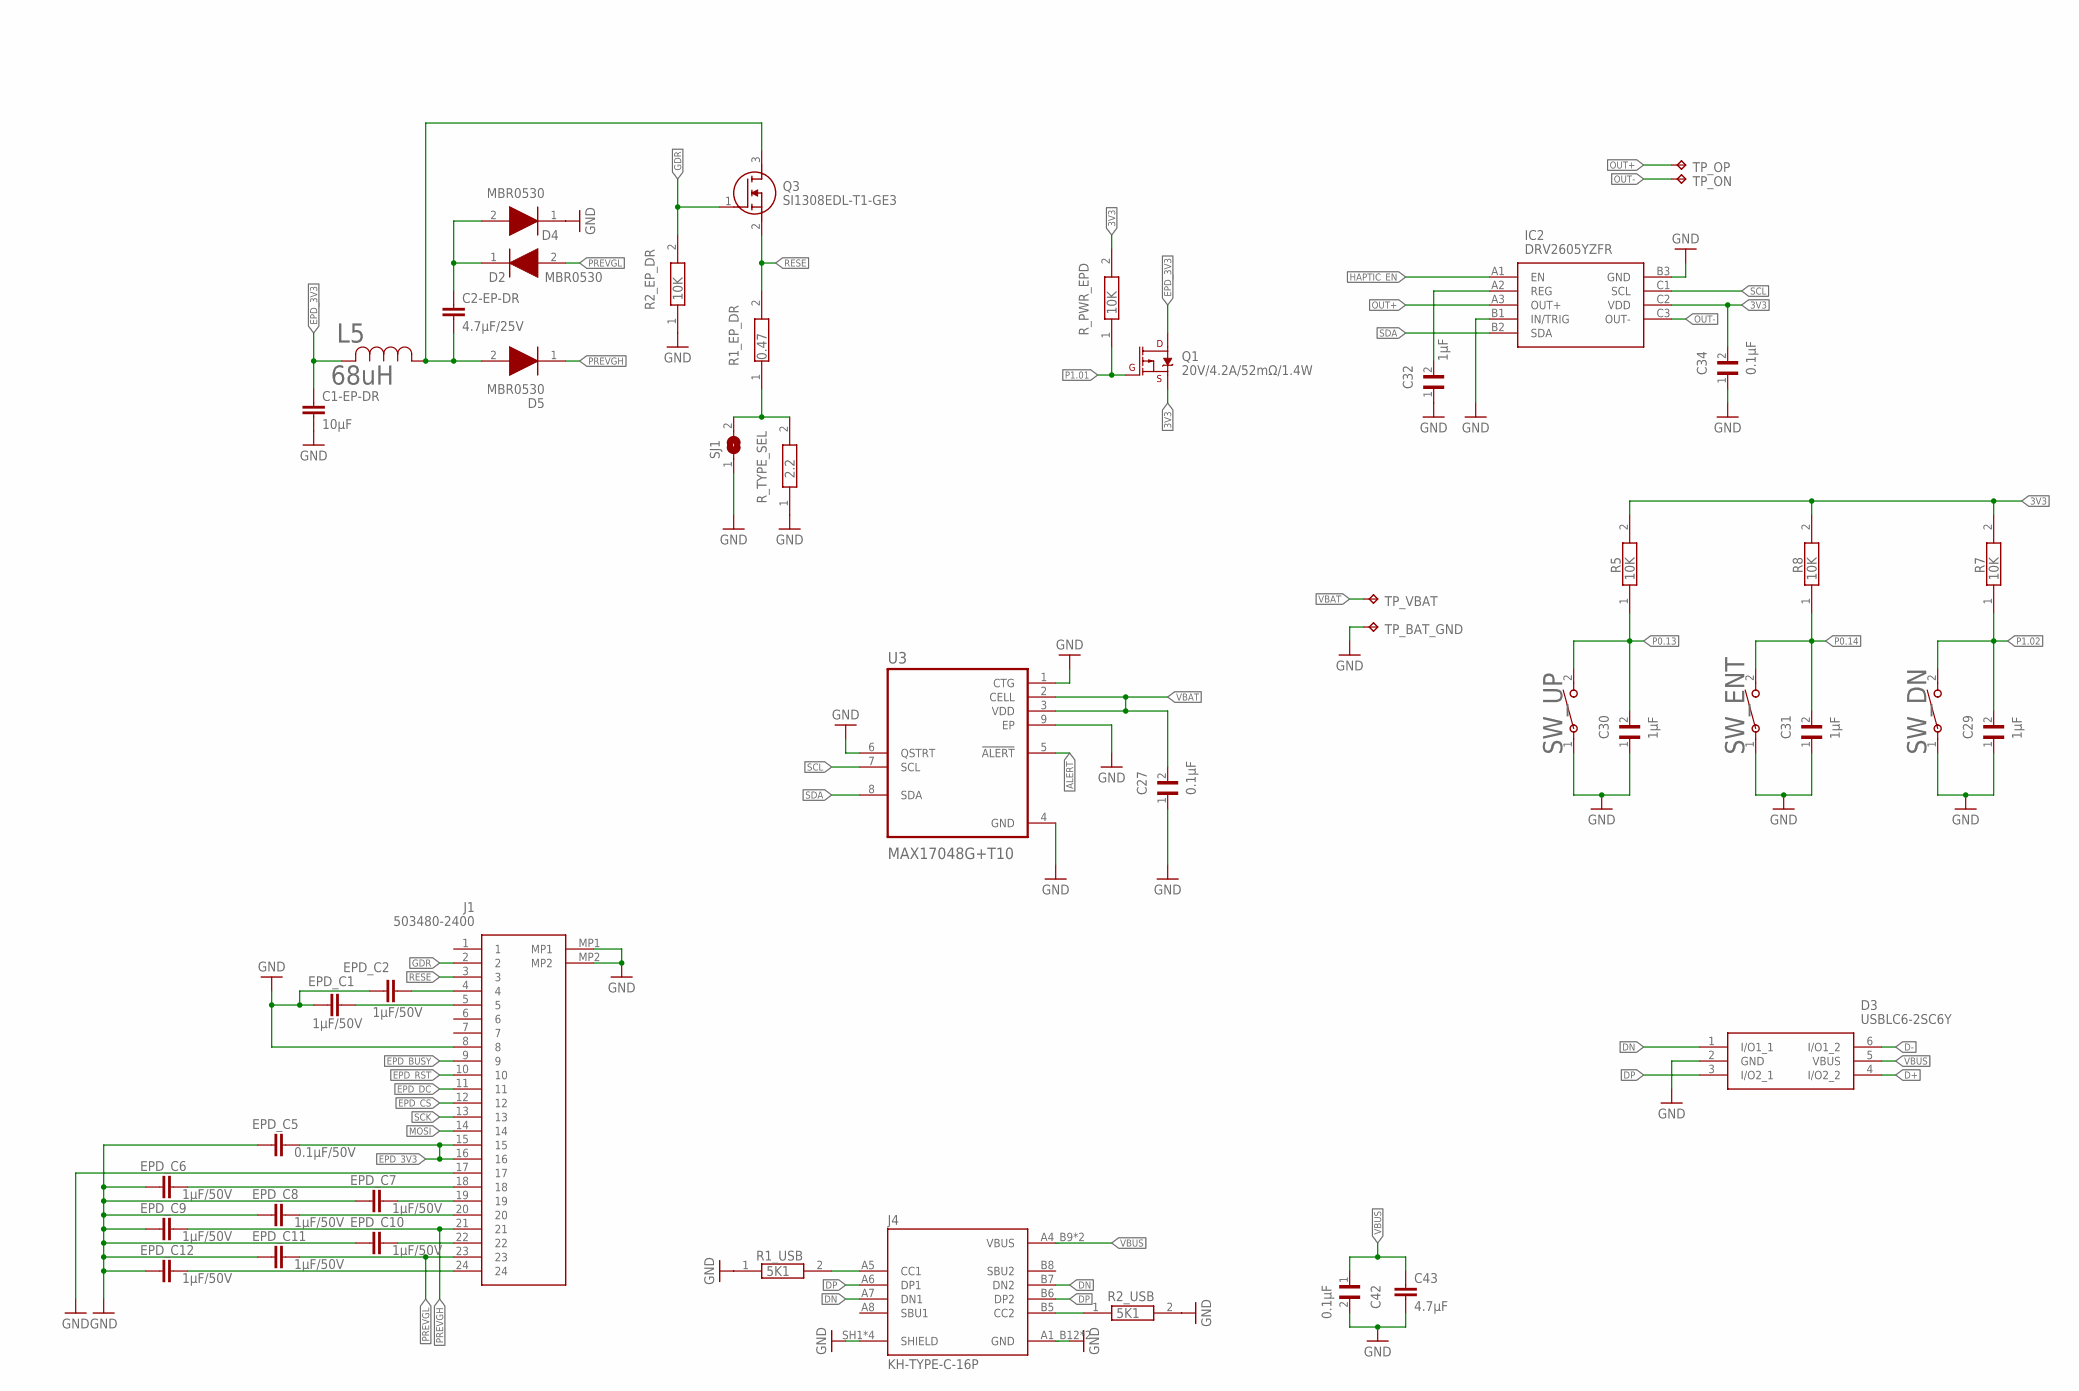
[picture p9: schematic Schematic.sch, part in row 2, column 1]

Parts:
ANT1: 2450AT18B100E; 2450AT18B100E_ANTC3216X140N
C1, C2, C17, C18: 12pF; NORDIC_NRF_3_RESC0201_L
C1-EP-DR, C24, C39: 10μF; NORDIC_NRF_3_RESC0402_L
C2-EP-DR: 4.7μF/25V; NORDIC_NRF_3_RESC0402_L
C3, C4: 1pF; NORDIC_NRF_3_RESC0201_L
C5, C7, C8, C12, C19: 100nF; NORDIC_NRF_3_RESC0201_L
C6, C14, C20, C21: 4.7µF; NORDIC_NRF_3_RESC0402_L
C9: 820pF; NORDIC_NRF_3_RESC0201_L
C10, C13, C22: N.C.; NORDIC_NRF_3_RESC0201_L
C11: 100pF; NORDIC_NRF_3_RESC0201_L
C15: 1.0µF; NORDIC_NRF_3_RESC0402_L
C16: 47nF; NORDIC_NRF_3_RESC0201_L
C23, C27, C34, C42: 0.1μF; GRM011R60J152KE01L_2_CAPC0201X13N
C25, C33: 22μF; NORDIC_NRF_3_RESC0402_L
C29, C30, C31, C32, C37, C38: 1μF; GRM011R60J152KE01L_2_CAPC0201X13N
C43: 4.7μF; NORDIC_NRF_3_RESC0402_L
D2, D4, D5: MBR0530; ESP32_C6_LIBRARY_5_SOD3716X135N
D3: USBLC6-2SC6Y; ESP32_C6_LIBRARY_3_SOT95P280X145-6N
EPD_C1, EPD_C2, EPD_C6, EPD_C7, EPD_C8, EPD_C9, EPD_C10, EPD_C11, EPD_C12: 1μF/50V; NORDIC_NRF_3_RESC0402_L
EPD_C5: 0.1μF/50V; NORDIC_NRF_3_RESC0201_L
IC1: BQ25180YBGR; BQ25180YBGR_BGA8C40P2X4_100X155X50
IC2: DRV2605YZFR; DRV2605YZFR_BGA9C50P3X3_144X144X62
IC3: BMA423_BMA423
IC9: RT6160AWSC; RT6160AWSC_BGA15C40P3X5_140X230X60
J1: 503480-2400; 503480-2400_5034802400
J2: TC2030-IDC; TC2030-IDC_TC2030IDC
J4: KH-TYPE-C-16P; KH-TYPE-C-16P_KINGHELM_KH-TYPE-C-16P
L1: 3.9nH; NORDIC_NRF_2_RESC0402_L
L2: 10µH; NORDIC_NRF_2_RESC0402_L
L3: 15nH; NORDIC_NRF_2_RESC0402_L
L5: 68uH; ESP32_C6_LIBRARY_2_IND_4828-WE-TPC_WRE
L7: NORDIC_NRF_2_INDUCTOR_0402_L; NORDIC_NRF_2_RESC0402_L
Q1: 20V/4.2A/52mΩ/1.4W; ESP32_C6_LIBRARY_4_ESP32_C6_LIBRARY_4_ESP32_C6_LIBRARY_4_ES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
Q3: SI1308EDL-T1-GE3; ESP32_C6_LIBRARY_6_SOT65P210X110-3N
R1_EP_DR: 0.47; CPF0201D7K68C1_0201
R1_USB, R2_USB: 5K1; CPF0201D7K68C1_0201
R2, R3, R4: 0; CPF0201D7K68C1_0201
R2_EP_DR, R5, R7, R8, R9: 10K; CPF0201D7K68C1_0201
R17, R18: 3K3; CPF0201D7K68C1_0201
R_PWR_EPD: 10K; CPF0201D7K68C1_0201
R_TYPE_SEL: 2.2; CPF0201D7K68C1_0201
SJ1: ESP32_C6_LIBRARY_7_JUMPER_SJ
SW_DN: 2025-10-22_07-23-44_LIBRARY_EVP-AKE31ASW_EVP-AKE3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; 2025-10-22_07-23-44_LIBRARY_SW_EVP-AKE31A_PAN
SW_ENT: 2025-10-22_07-23-44_LIBRARY_EVP-AKE31ASW_EVP-AKE3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; 2025-10-22_07-23-44_LIBRARY_SW_EVP-AKE31A_PAN
SW_UP: 2025-10-22_07-23-44_LIBRARY_EVP-AKE31ASW_EVP-AKE3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; 2025-10-22_07-23-44_LIBRARY_SW_EVP-AKE31A_PAN
TP_3.3V, TP_3V3: HECTOR_WATCH_1_TPTP20R; HECTOR_WATCH_1_TP20R
TP_BAT_GND: HECTOR_WATCH_1_TPTP20R; HECTOR_WATCH_1_TP20R
TP_GND: HECTOR_WATCH_1_TPTP20R; HECTOR_WATCH_1_TP20R
TP_ON: HECTOR_WATCH_1_TPTP20R; HECTOR_WATCH_1_TP20R
TP_OP: HECTOR_WATCH_1_TPTP20R; HECTOR_WATCH_1_TP20R
TP_RESET: HECTOR_WATCH_1_TPTP20R; HECTOR_WATCH_1_TP20R
TP_SCL: HECTOR_WATCH_1_TPTP20R; HECTOR_WATCH_1_TP20R
TP_SDA: HECTOR_WATCH_1_TPTP20R; HECTOR_WATCH_1_TP20R
TP_SWDCLK: HECTOR_WATCH_1_TPTP20R; HECTOR_WATCH_1_TP20R
TP_SWDIO: HECTOR_WATCH_1_TPTP20R; HECTOR_WATCH_1_TP20R
TP_SWO: HECTOR_WATCH_1_TPTP20R; HECTOR_WATCH_1_TP20R
TP_VBAT: HECTOR_WATCH_1_TPTP20R; HECTOR_WATCH_1_TP20R
TP_VREG: HECTOR_WATCH_1_TPTP20R; HECTOR_WATCH_1_TP20R
U1: NORDIC_NRF_4_NRF52840_QF; NORDIC_NRF_4_AQFN50P700X700X85_HS-74N
U3: MAX17048G+T10; ESP32_C6_LIBRARY_SON50P200X200X80-9N
X1: 32MHz; NORDIC_NRF_BT-XTAL_2016_N
X2: 32.768kHz; NORDIC_NRF_1_XTAL_3215_N

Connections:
3V3: C6.1, C7.1, C8.1, C12.1, C14.1, C19.1, C25.1, C33.1, C34.2, IC2.C2 (VDD), IC3.3 (VDDIO), IC3.7 (VDD), IC3.10 (CSB), IC9.E2 (VOUT_1), IC9.E3 (VOUT_2), J2.1, Q1.2 (S), R5.2, R7.2, R8.2, R17.1, R18.1, R_PWR_EPD.2, TP_3.3V.TP, TP_3V3.TP, U1.P$A22 (VDD), U1.P$AD14 (VDD), U1.P$AD23 (VDD), U1.P$B1 (VDD), U1.P$W1 (VDD), U1.P$Y2 (VDDH)
ALERT: U1.P$J24 (P0.10/NFC2), U3.5 (!ALERT)
D+: D3.4 (I/O2_2), U1.P$AD6 (D+)
D-: D3.6 (I/O1_2), U1.P$AD4 (D-)
DEC1: C5.1, U1.P$C1 (DEC1)
DEC3: C11.1, U1.P$D23 (DEC3)
DEC4_6: C10.1, C15.1, C16.1, L3.2, U1.P$B5 (DEC4), U1.P$E24 (DEC6)
DN: D3.1 (I/O1_1), J4.A7 (DN1), J4.B7 (DN2)
DP: D3.3 (I/O2_1), J4.A6 (DP1), J4.B6 (DP2)
EPD_3V3: C1-EP-DR.1, EPD_C5.2, J1.15, J1.16, L5.2, Q1.3 (D)
EPD_BUSY: J1.9, U1.P$AD12 (P0.17)
EPD_CS: J1.12, U1.P$K2 (P0.05/AIN3)
EPD_DC: J1.11, U1.P$AD10 (P0.15)
EPD_RST: J1.10, U1.P$AC11 (P0.16)
GDR: J1.2, Q3.1 (G), R2_EP_DR.2
GND: C1.2, C1-EP-DR.2, C2.2, C3.2, C4.2, C5.2, C6.2, C7.2, C8.2, C9.2, C10.2, C11.2, C12.2, C13.2, C14.2, C15.2, C16.2, C17.1, C18.1, C19.2, C20.2, C21.2, C22.2, C23.1, C24.1, C25.2, C27.1, C29.1, C30.1, C31.1, C32.1, C33.2, C34.1, C37.1, C38.1, C39.2, C42.2, C43.2, D3.2 (GND), D4.1 (K), EPD_C1.1, EPD_C2.1, EPD_C5.1, EPD_C6.2, EPD_C7.2, EPD_C8.2, EPD_C9.2, EPD_C10.2, EPD_C11.2, EPD_C12.2, IC1.D2 (GND), IC2.B1 (IN/TRIG), IC2.B3 (GND), IC3.8 (GNDIO), IC3.9 (GND), IC9.B1 (VSEL), IC9.C1 (AGND), IC9.C2 (PGND_1), IC9.C3 (PGND_2), J1.8, J1.17, J1.MP1, J1.MP2, J2.3, J2.5, J4.A1_B12 (GND), J4.A12_B1 (GND), J4.SH1 (SHIELD), J4.SH2 (SHIELD), J4.SH3 (SHIELD), J4.SH4 (SHIELD), R1_USB.1, R2_EP_DR.1, R2_USB.2, R3.1, R9.1, R_TYPE_SEL.1, SJ1.1, SW_DN.1, SW_ENT.1, SW_UP.1, TP_BAT_GND.TP, TP_GND.TP, U1.P$74 (VSS_PAD), U1.P$75 (VSS_PAD), U1.P$76 (VSS_PAD), U1.P$77 (VSS_PAD), U1.P$78 (VSS_PAD), U1.P$79 (VSS_PAD), U1.P$80 (VSS_PAD), U1.P$81 (VSS_PAD), U1.P$82 (VSS_PAD), U1.P$83 (VSS_PAD), U1.P$84 (VSS_PAD), U1.P$85 (VSS_PAD), U1.P$86 (VSS_PAD), U1.P$87 (VSS_PAD), U1.P$88 (VSS_PAD), U1.P$89 (VSS_PAD), U1.P$90 (VSS_PAD), U1.P$B7 (VSS), U1.P$F23 (VSS_PA), U3.1 (CTG), U3.4 (GND), U3.6 (QSTRT), U3.9 (EP), X1.2, X1.4
HAPTIC_EN: IC2.A1 (EN), U1.P$U1 (P0.12)
IMU_INT1: IC3.5 (INT1), U1.P$N1 (P0.08)
IMU_INT2: IC3.6 (INT2), U1.P$P2 (P1.08)
LX1: IC9.B2 (SW1_1), IC9.B3 (SW1_2), L7.1
LX2: IC9.D2 (SW2_1), IC9.D3 (SW2_2), L7.2
MOSI: J1.14, U1.P$B13 (P0.03/AIN1)
unnamed: C9.1, U1.P$N24 (DEC5)
unnamed: ANT1.1 (FEED), C4.1, C22.1, L1.2
unnamed: C3.1, L1.1, U1.P$H23 (ANT)
unnamed: C13.1, U1.P$A18 (DEC2)
unnamed: C2.1, U1.P$A23 (XC2), X1.3
unnamed: C1.1, U1.P$B24 (XC1), X1.1
unnamed: L2.2, L3.1
unnamed: L2.1, U1.P$B3 (DCC)
unnamed: C18.2, U1.P$F2 (P0.01/XL2), X2.2
unnamed: C17.2, U1.P$D2 (P0.00/XL1), X2.1
unnamed: IC3.1 (SDO), R3.2
unnamed: C20.1, U1.P$AC5 (DEC3V3)
unnamed: IC1.D1 (TS/MR), R9.2
unnamed: IC9.D1 (SCL), R4.2
unnamed: IC9.E1 (SDA), R2.2
unnamed: R1_EP_DR.1, R_TYPE_SEL.2, SJ1.2
unnamed: C2-EP-DR.1, D2.1 (K), D4.2 (A)
unnamed: EPD_C2.2, J1.4
unnamed: C2-EP-DR.2, D5.2 (A), L5.1, Q3.3 (D)
unnamed: EPD_C1.2, J1.5
unnamed: EPD_C6.1, J1.18
unnamed: C32.2, IC2.A2 (REG)
unnamed: EPD_C7.1, J1.19
unnamed: EPD_C8.1, J1.20
unnamed: EPD_C10.1, J1.22
unnamed: EPD_C12.1, J1.24
unnamed: J4.B5 (CC2), R2_USB.1
unnamed: J4.A5 (CC1), R1_USB.2
OUT+: IC2.A3 (OUT+), TP_OP.TP
OUT-: IC2.C3 (OUT-), TP_ON.TP
P0.04: U1.P$J1 (P0.04/AIN2)
P0.09: U1.P$L24 (P0.09/NFC1)
P0.13: C30.2, R5.1, SW_UP.2, U1.P$AD8 (P0.13)
P0.14: C31.2, R8.1, SW_ENT.2, U1.P$AC9 (P0.14)
P0.19: U1.P$AC15 (P0.19)
P0.20: U1.P$AD16 (P0.20)
P0.21: U1.P$AC17 (P0.21)
P0.22: U1.P$AD18 (P0.22)
P0.23: U1.P$AC19 (P0.23)
P0.24: U1.P$AD20 (P0.24)
P0.25: U1.P$AC21 (P0.25)
P0.26: U1.P$G1 (P0.26)
P0.27: U1.P$H2 (P0.27)
P0.28: U1.P$B11 (P0.28/AIN4)
P0.29: U1.P$A10 (P0.29/AIN5)
P0.30: U1.P$B9 (P0.30/AIN6)
P0.31: U1.P$A8 (P0.31/AIN7)
P1.01: Q1.1 (G), R_PWR_EPD.1, U1.P$Y23 (P1.01)
P1.02: C29.2, R7.1, SW_DN.2, U1.P$W24 (P1.02)
P1.03: U1.P$V23 (P1.03)
P1.04: U1.P$U24 (P1.04)
P1.05: U1.P$T23 (P1.05)
P1.06: U1.P$R24 (P1.06)
P1.07: U1.P$P23 (P1.07)
P1.09: U1.P$R1 (P1.09)
P1.10: U1.P$A20 (P1.10)
P1.11: U1.P$B19 (P1.11)
P1.12: U1.P$B17 (P1.12)
P1.13: U1.P$A16 (P1.13)
P1.14: U1.P$B15 (P1.14)
P1.15: U1.P$A14 (P1.15)
PMIC_INT: IC1.A1 (!INT), U1.P$T2 (P0.11)
PREVGH: D5.1 (K), EPD_C9.1, J1.21
PREVGL: D2.2 (A), EPD_C11.1, J1.23
RESE: J1.3, Q3.2 (S), R1_EP_DR.2
RESET: J2.6, TP_RESET.TP, U1.P$AC13 (P0.18/RESET)
SCK: J1.13, U1.P$A12 (P0.02/AIN0)
SCL: IC1.B1 (SCL), IC2.C1 (SCL), IC3.12 (SCX), R4.1, R17.2, TP_SCL.TP, U1.P$M2 (P0.07), U3.7 (SCL)
SDA: IC1.C1 (SDA), IC2.B2 (SDA), IC3.2 (SDX), R2.1, R18.2, TP_SDA.TP, U1.P$L1 (P0.06), U3.8 (SDA)
SWDCLK: J2.4, TP_SWDCLK.TP, U1.P$AA24 (SWDCLK)
SWDIO: J2.2, TP_SWDIO.TP, U1.P$AC24 (SWDIO)
SWO: TP_SWO.TP, U1.P$AD22 (P1.00)
VBAT: C27.2, C37.2, IC1.C2 (BAT), TP_VBAT.TP, U3.2 (CELL), U3.3 (VDD)
VBUS: C21.1, C38.2, C42.1, C43.1, D3.5 (VBUS), IC1.A2 (IN), J4.A4_B9 (VBUS), J4.A9_B4 (VBUS), U1.P$AD2 (VBUS)
VREG: C23.2, C24.2, C39.1, IC1.B2 (SYS), IC9.A1 (EN), IC9.A2 (VIN_1), IC9.A3 (VIN_2), TP_VREG.TP

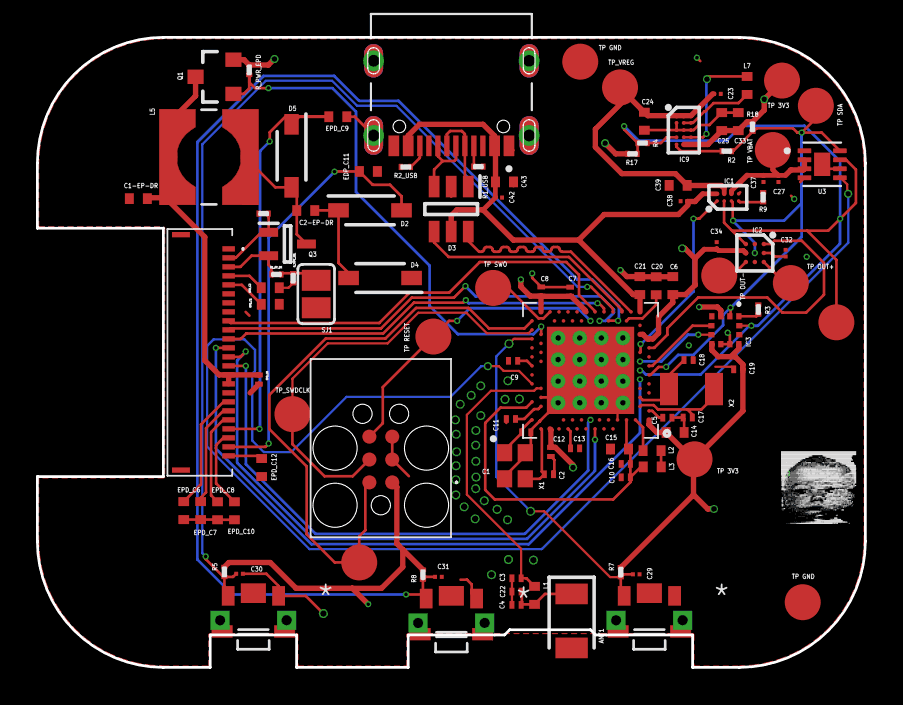
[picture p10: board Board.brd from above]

Board: 4 copper layers, 46.0 x 35.0 mm, 105 parts (0 on the bottom side), 70 nets.

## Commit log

2026-04-17 Final stuff
    [pick_and_place.csv]
2026-04-21 Antenna Cutout & Frames
    [Board.brd, Schematic.sch]

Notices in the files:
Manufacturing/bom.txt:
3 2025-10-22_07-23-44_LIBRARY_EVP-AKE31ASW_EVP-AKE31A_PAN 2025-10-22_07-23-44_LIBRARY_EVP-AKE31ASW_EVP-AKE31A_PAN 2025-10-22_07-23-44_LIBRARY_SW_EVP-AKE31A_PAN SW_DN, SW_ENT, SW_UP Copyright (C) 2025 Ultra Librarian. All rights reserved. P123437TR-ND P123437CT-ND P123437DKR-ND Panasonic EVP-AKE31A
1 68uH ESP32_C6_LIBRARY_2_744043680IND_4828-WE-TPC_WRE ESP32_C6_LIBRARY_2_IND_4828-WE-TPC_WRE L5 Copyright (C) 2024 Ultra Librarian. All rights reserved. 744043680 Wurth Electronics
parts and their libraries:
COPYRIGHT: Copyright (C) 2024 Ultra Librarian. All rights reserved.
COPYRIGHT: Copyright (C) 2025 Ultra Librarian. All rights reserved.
